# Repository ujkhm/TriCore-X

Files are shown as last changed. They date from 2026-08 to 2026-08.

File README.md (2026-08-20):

# Xeltri

> **Xeltri: a heterogeneous development board.**
> X = mixed heterogeneous cores, el = electronics, tri = three cores (MPU + MCU + FPGA).
> This board puts an FPGA, an MPU, and an MCU on one system. (in development)

#### Read the original Traditional Chinese version [here](README.zh-TW.md).

**Hackaday.io Project Page:** [Xeltri - Pick and Place Control Board](https://hackaday.io/project/206451-xeltri-pick-and-place-control-board)

---

### Project overview
This project is a main controller board built for a desktop pick-and-place (PnP) machine. The three cores — STM32H745XIH6 (MCU), XC7A35T-2CSG325C (FPGA), and V851S (MPU) — are locked in and work together. Expansion I/O so far: PCIe 2.1 ×2 (in a PCIe ×4 slot, wired to the FPGA) and a microSD card slot. Everything else is still TBD.

---

### How it started
I needed a pick-and-place machine, but buying one was too expensive, so I decided to build it myself. I was 15 when I started (25 June 2026). It began as a sudden “what if I just try?” thought, and I then committed to it as a long-term project. A lot of what this board needs is something I only know *what it is for*, not something I have actually designed before. I know this is hard, so please keep expectations modest — but it should not be terrible either.

---

### Board architecture and why these cores
Xeltri is built around STM32H745XIH6 (MCU), XC7A35T-2CSG325C (FPGA), and V851S (MPU). I chose this trio because I want to try mixed alignment: pure optical alignment for simple parts (0805, 0402, and similar packages), and a vision camera (OpenCV-style) for complex parts. I also want up-looking / down-looking cameras plus on-device AI for machine-health checks — that is why V851S is in the mix.

I am using pure optical alignment on simple parts because I want industrial on-the-fly (“flying shot”) speed, and the vision hardware that can actually do that is far too expensive. Optical alignment is much cheaper, but it needs real-time performance. The machine is meant to be a box-style CoreXY so it takes less floor space (like a Voron printer), which means a lot of structure and a lot of stepper motors to control. Closed-loop steppers with the servo drive in the motor base are too expensive for me, and the cheap ones are not fast enough. An FPGA can handle that and more — I want the finished machine to be strong, not merely usable. That is how this three-core combination ended up here.

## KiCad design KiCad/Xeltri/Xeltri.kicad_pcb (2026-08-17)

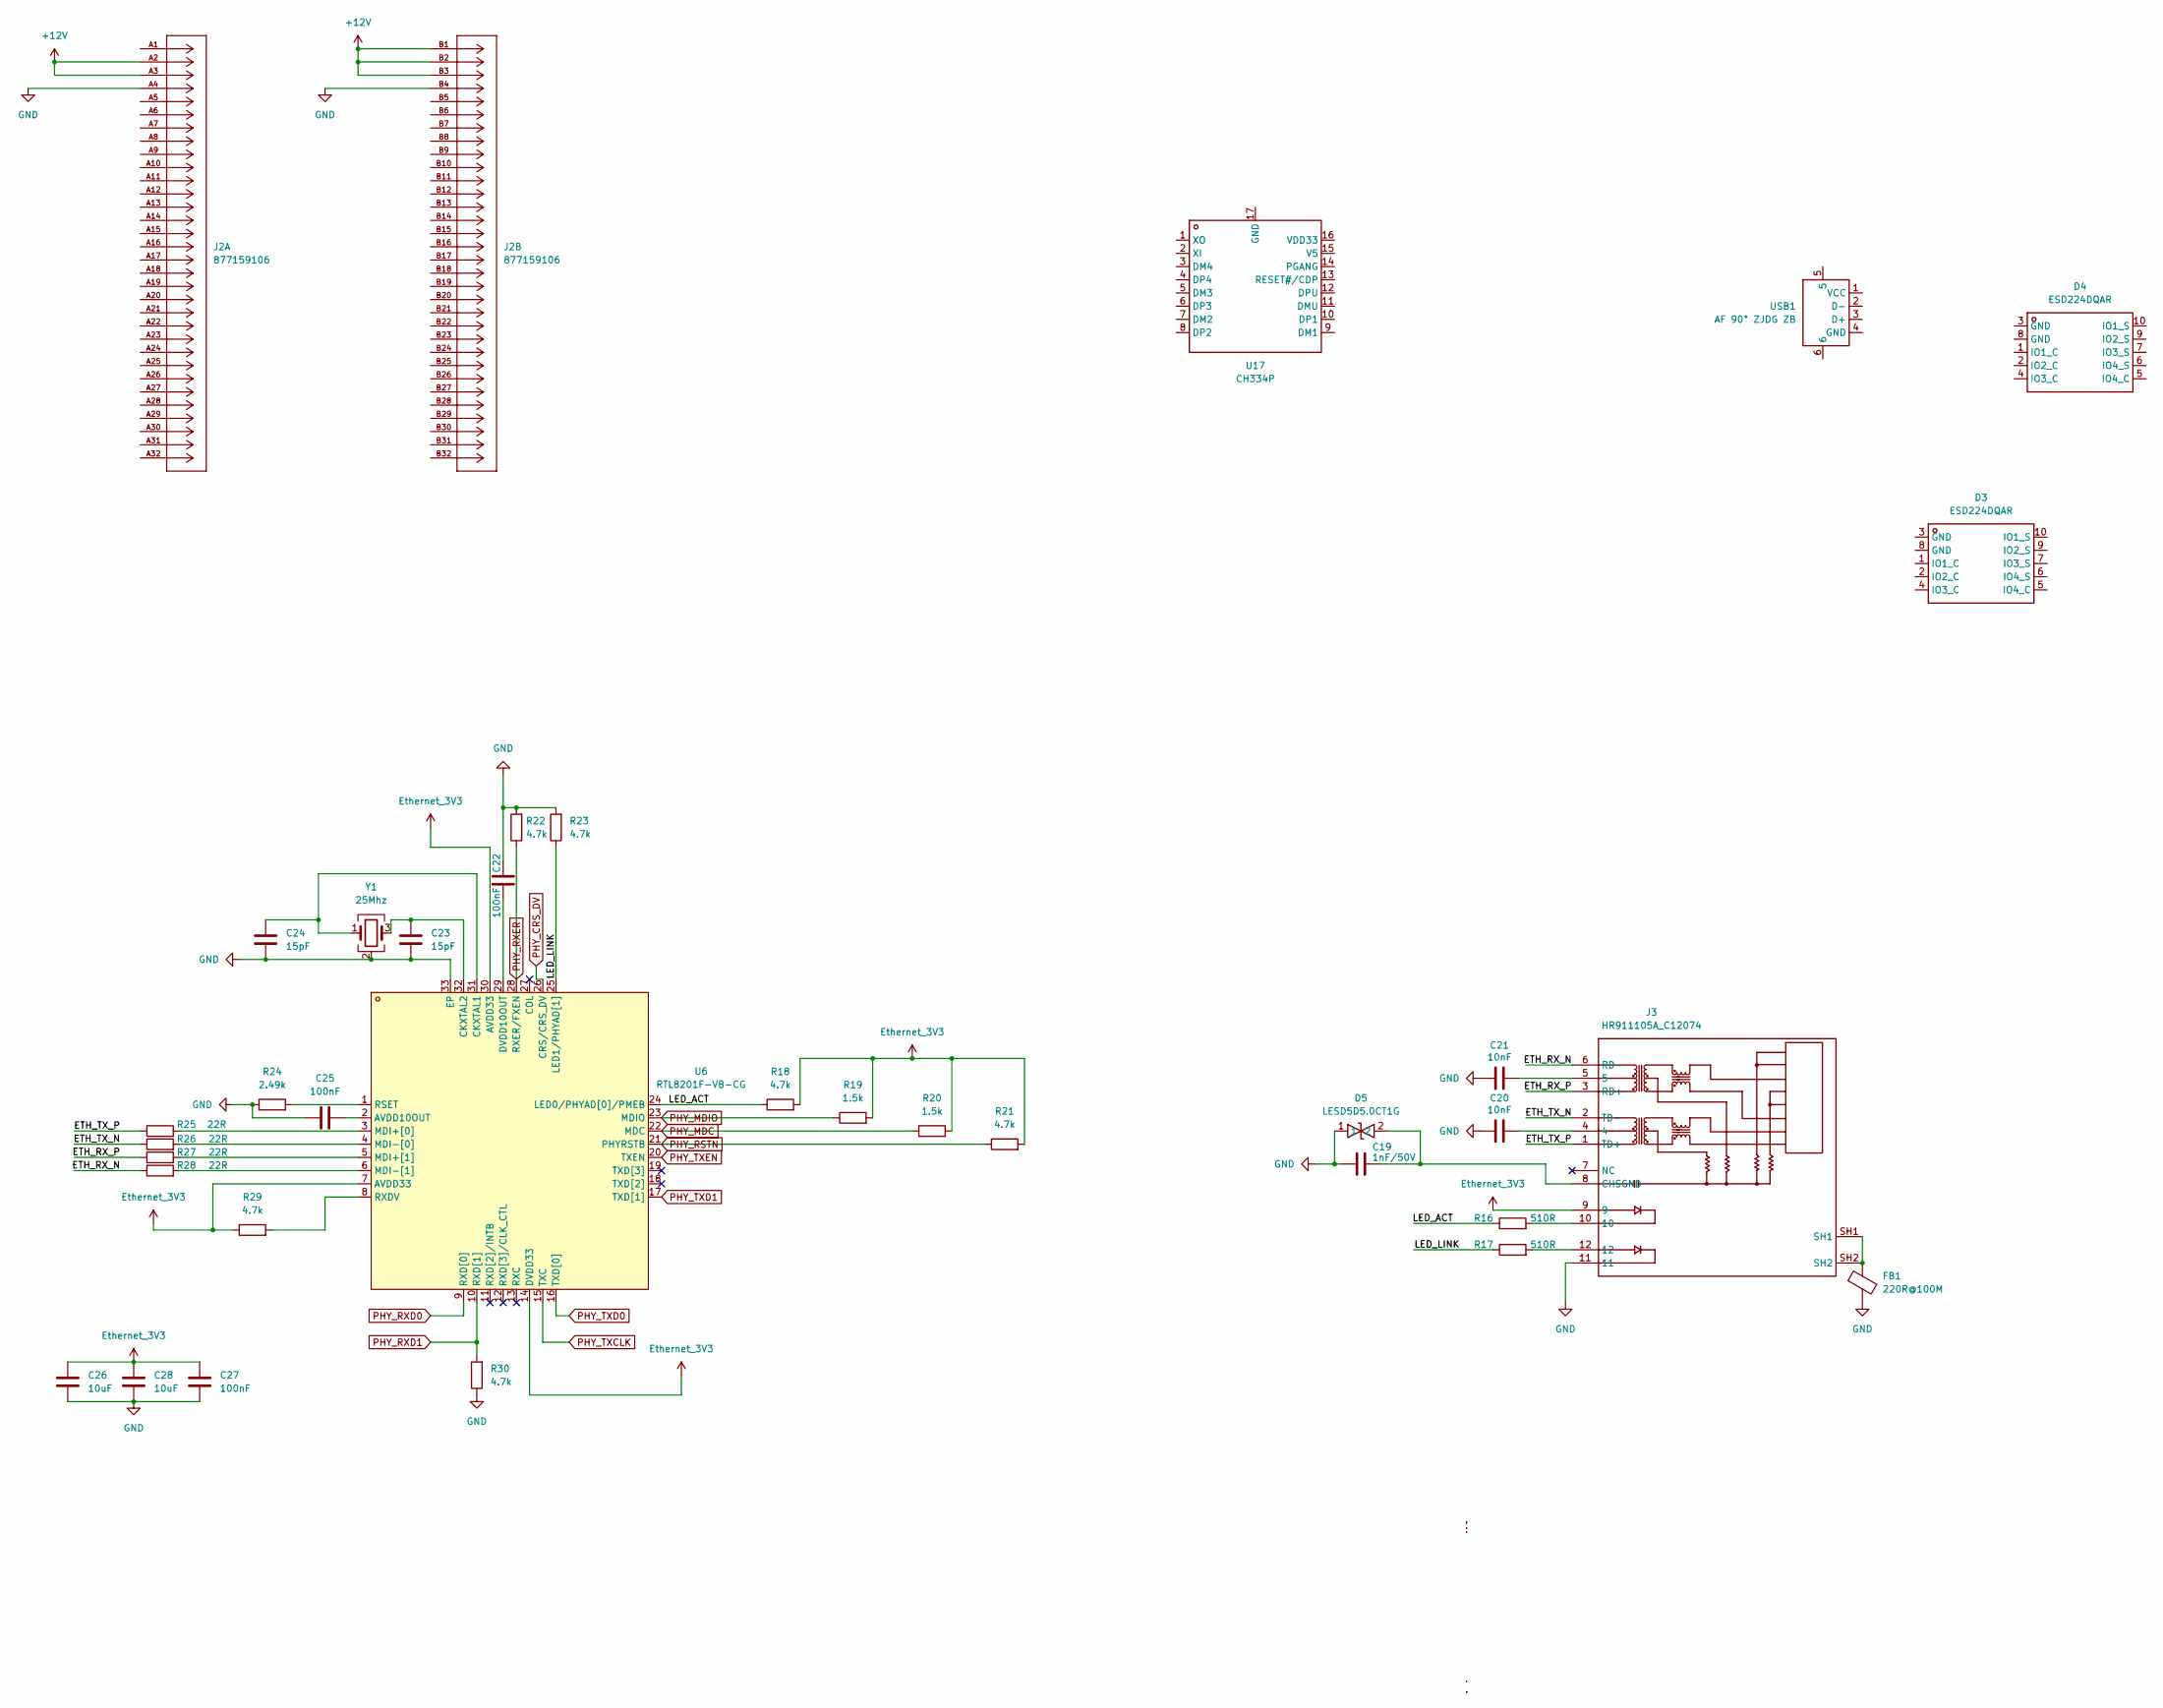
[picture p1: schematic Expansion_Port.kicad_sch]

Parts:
C19: 1nF/50V; C_0402_1005Metric
C20, C21: 10nF; C_0402_1005Metric
C22, C25, C27: 100nF; C_0402_1005Metric
C23, C24: 15pF; C_0402_1005Metric
C26, C28: 10uF; C_0402_1005Metric
D3, D4: ESD224DQAR; USON-10_L2.5-W1.0-P0.50-BL; LCSC Part C1981316
D5: LESD5D5.0CT1G; SOD-523_L1.2-W0.8-LS1.6-BI; LCSC Part C383211
FB1: 220R@100M; L_0603_1608Metric
J2: 877159106; CONN_87715-9106_MOL; MANUFACTURER_PART_NUMBER 877159106
J3: HR911105A_C12074; RJ45-TH_HR911105A; LCSC Part C12074
R16, R17: 510R; R_0402_1005Metric
R18, R21, R22, R23, R29, R30: 4.7k; R_0402_1005Metric
R19, R20: 1.5k; R_0402_1005Metric
R24: 2.49k; R_0402_1005Metric
R25, R26, R27, R28: 22R; R_0402_1005Metric
U6: RTL8201F-VB-CG; QFN-32_L5.0-W5.0-P0.50-BL-EP3.4; MPN RTL8201F-VB-CG; LCSC Part C45044
U17: CH334P; QFN-16_L3.0-W3.0-P0.50-BL-EP1.7; LCSC Part C5373042
USB1: AF 90° ZJDG ZB; USB-A-TH_AF-90-ZJDG-ZB; LCSC Part C6332182
Y1: 25Mhz; Crystal_SMD_3225-4Pin_3.2x2.5mm

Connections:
+12V: J2.A2, J2.A3, J2.B1, J2.B2, J2.B3; also elsewhere on the board
/Expansion_Port/ETH_RX_N: J3.6 (RD-), R28.1
/Expansion_Port/ETH_RX_P: J3.3 (RD+), R27.1
/Expansion_Port/ETH_TX_N: J3.2 (TD-), R26.1
/Expansion_Port/ETH_TX_P: J3.1 (TD+), R25.1
/Expansion_Port/LED_ACT: R16.1, R18.1, U6.24 (LED0/PHYAD[0]/PMEB)
/Expansion_Port/LED_LINK: R17.1, R23.1, U6.25 (LED1/PHYAD[1])
Ethernet_3V3: C26.1, C27.1, C28.1, J3.9, R18.2, R19.2, R20.2, R21.2, R29.1, U6.7 (AVDD33), U6.14 (DVDD33), U6.30 (AVDD33)
GND: C19.1, C20.1, C21.1, C22.2, C23.1, C24.1, C25.1, C26.2, C27.2, C28.2, D5.1, FB1.2, J2.A4, J2.B4, J3.11, R22.2, R23.2, R24.1, R30.1, U6.33 (EP), Y1.2 (G), Y1.4 (G); also elsewhere on the board
unnamed: C20.2, J3.4
unnamed: C21.2, J3.5
unnamed: FB1.1, J3.SH1, J3.SH2
unnamed: C19.2, D5.2, J3.8 (CHSGND)
unnamed: J3.10, R16.2
unnamed: J3.12, R17.2
unnamed: C25.2, U6.2 (AVDD10OUT)
unnamed: C24.2, U6.31 (CKXTAL1), Y1.1
unnamed: C23.2, U6.32 (CKXTAL2), Y1.3
unnamed: C22.1, U6.29 (DVDD10OUT)
unnamed: R25.2, U6.3 (MDI+[0])
unnamed: R27.2, U6.5 (MDI+[1])
unnamed: R26.2, U6.4 (MDI-[0])
unnamed: R28.2, U6.6 (MDI-[1])
unnamed: R24.2, U6.1 (RSET)
unnamed: R29.2, U6.8 (RXDV)
PHY_CRS_DV: U6.26 (CRS/CRS_DV)
PHY_MDC: R20.1, U6.22 (MDC)
PHY_MDIO: R19.1, U6.23 (MDIO)
PHY_RSTN: R21.1, U6.21 (PHYRSTB)
PHY_RXD0: U6.9 (RXD[0])
PHY_RXD1: R30.2, U6.10 (RXD[1])
PHY_RXER: R22.1, U6.28 (RXER/FXEN)
PHY_TXCLK: U6.15 (TXC)
PHY_TXD0: U6.16 (TXD[0])
PHY_TXD1: U6.17 (TXD[1])
PHY_TXEN: U6.20 (TXEN)

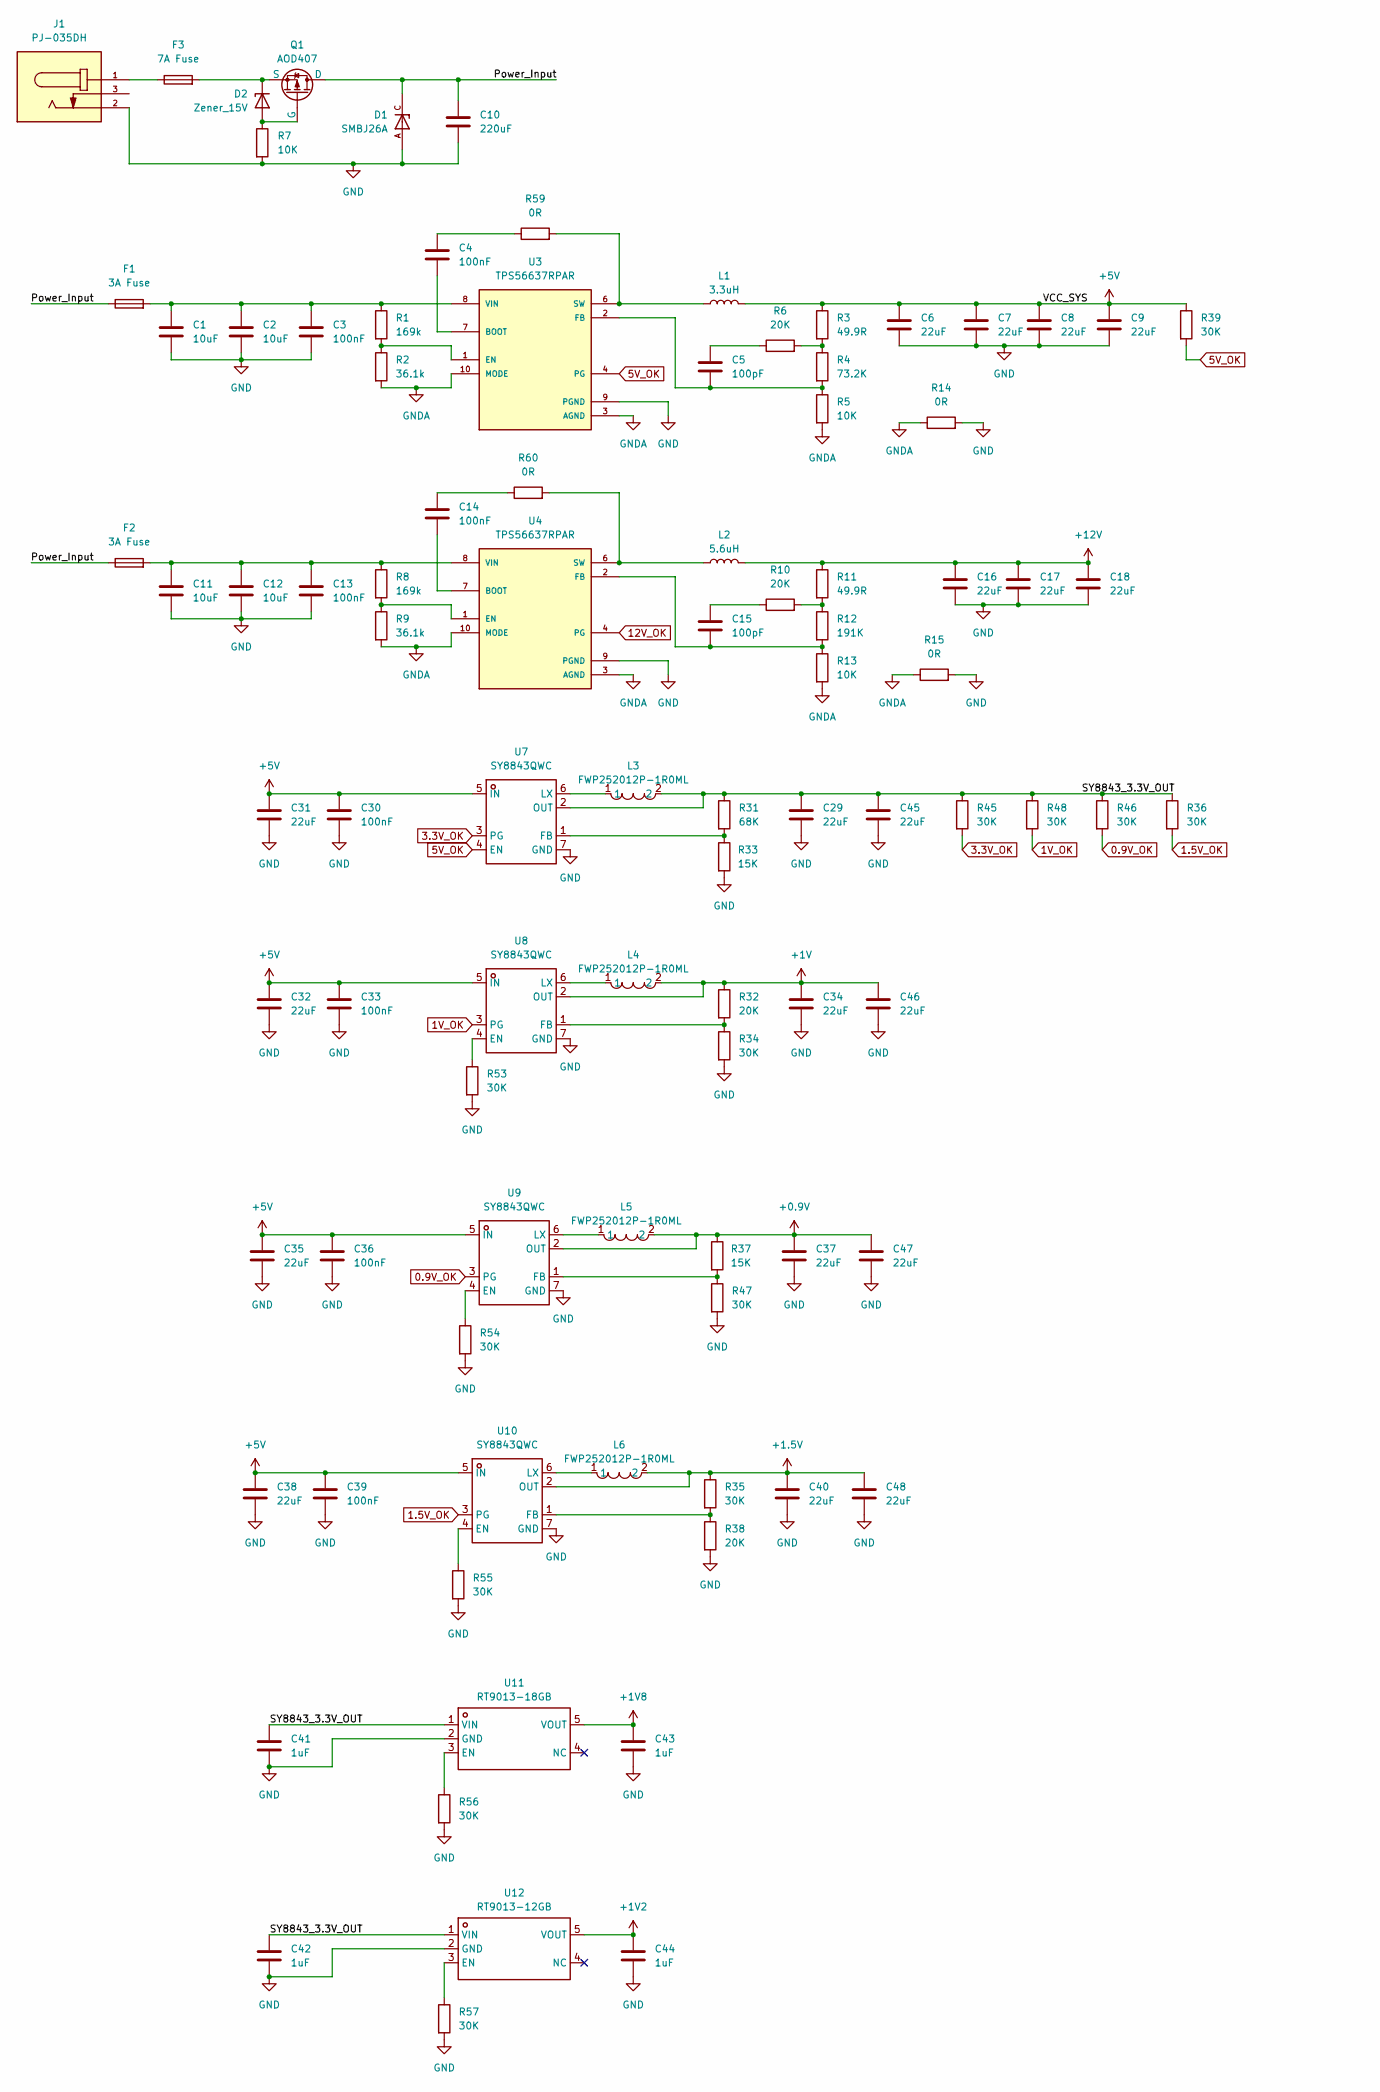
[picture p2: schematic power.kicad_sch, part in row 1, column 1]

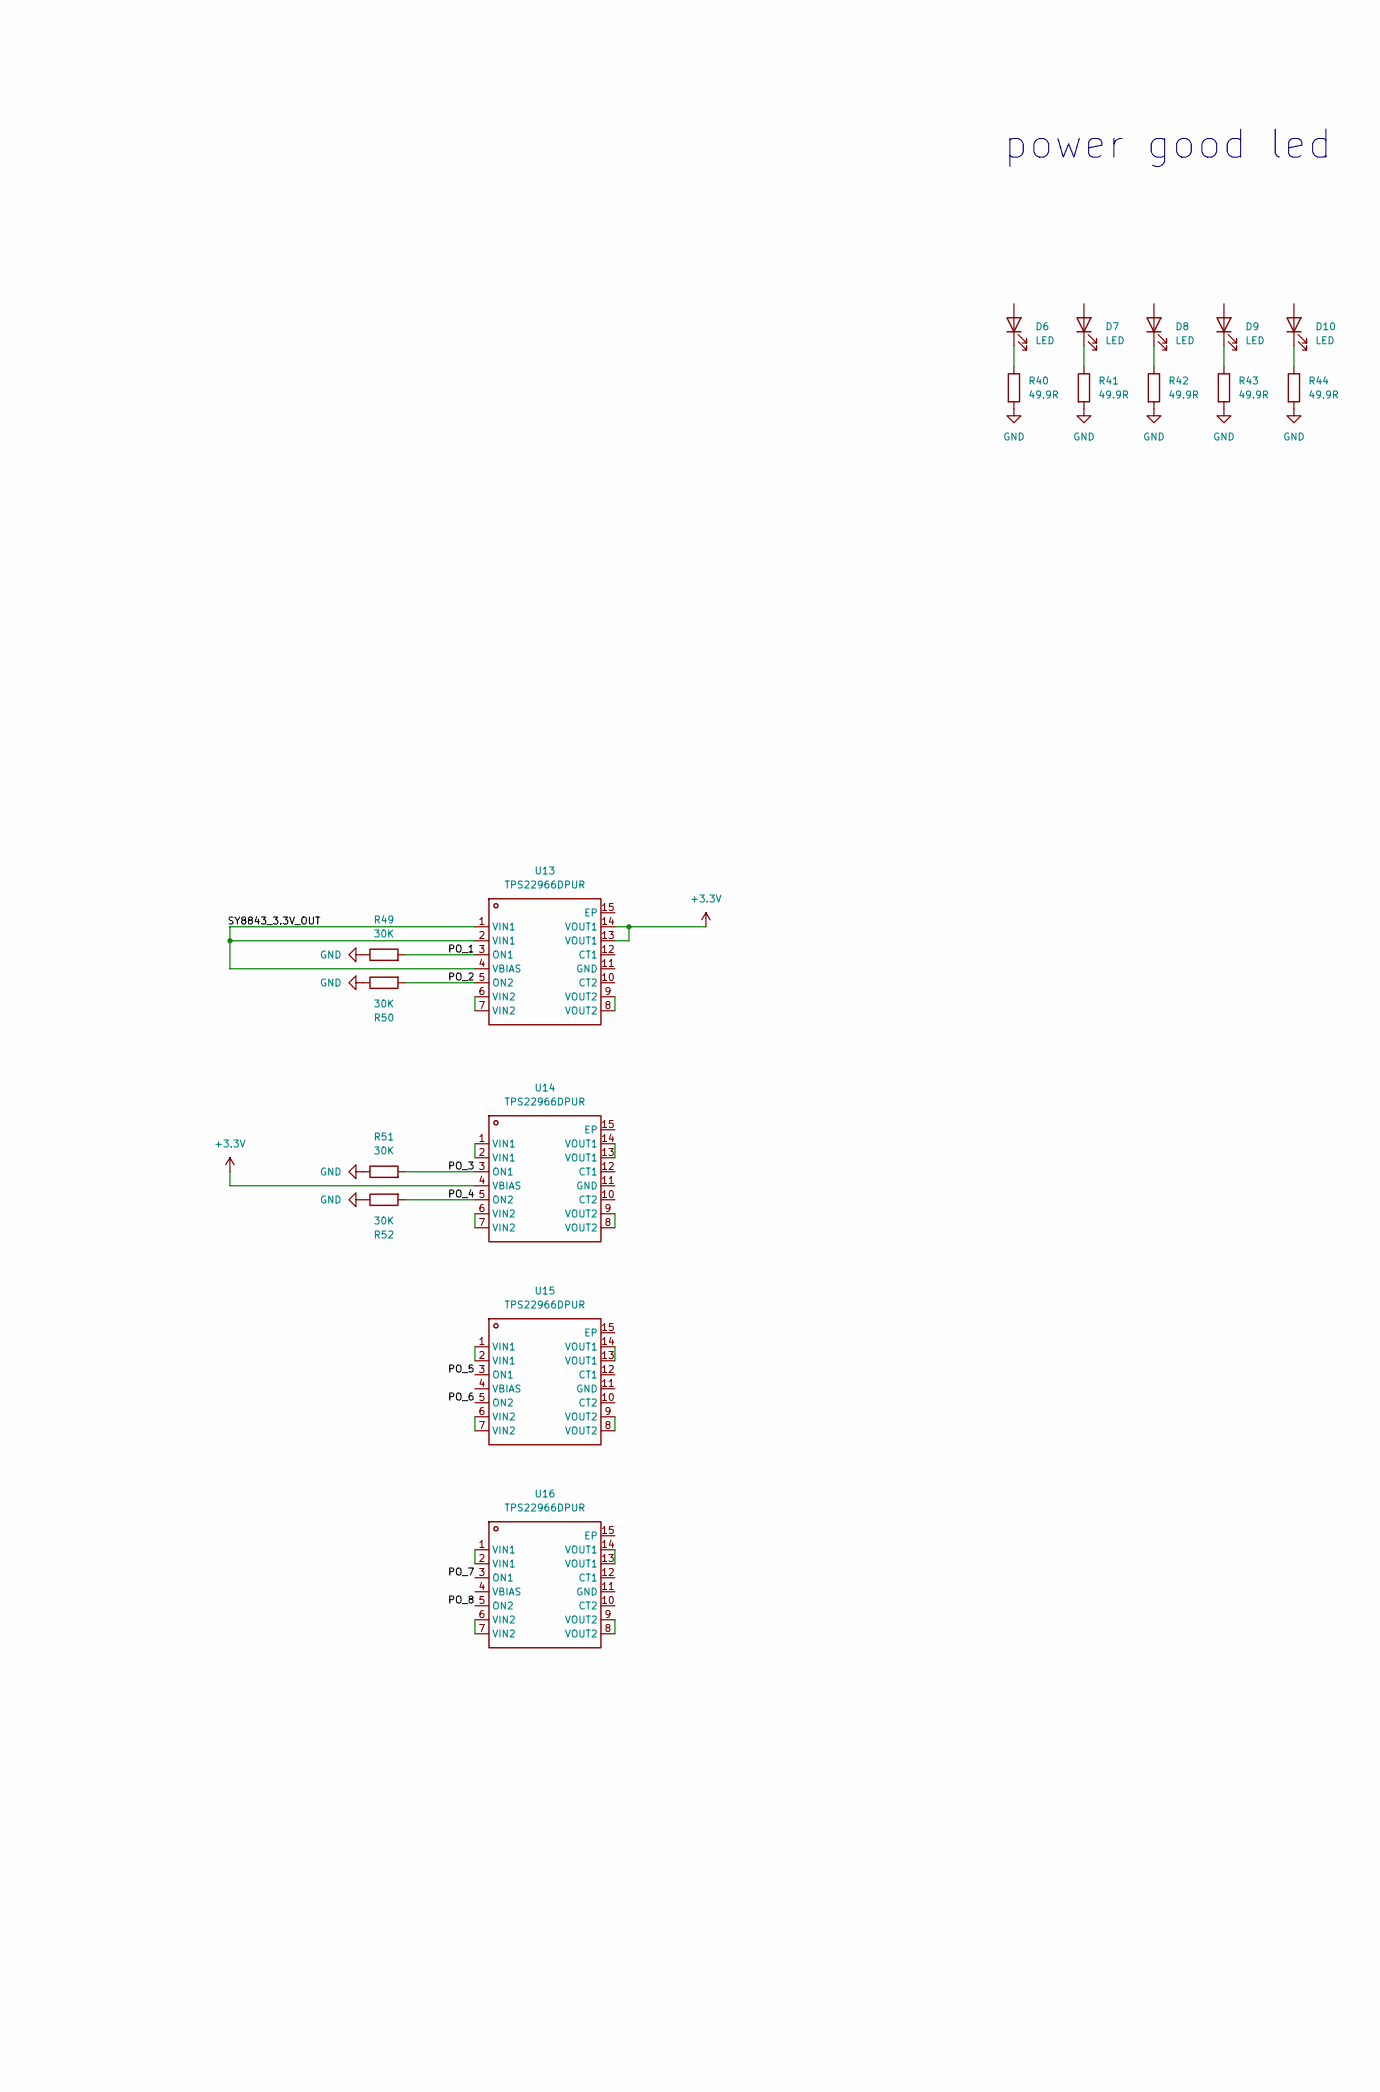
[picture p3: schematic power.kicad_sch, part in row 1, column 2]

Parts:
C1, C2, C11, C12: 10uF; C_1210_3225Metric
C3, C13: 100nF; C_0805_2012Metric
C4, C14, C30, C33, C36, C39: 100nF; C_0402_1005Metric
C5, C15: 100pF; C_0402_1005Metric
C6, C7, C8, C9, C16, C17, C18, C29, C31, C32, C34, C35, C37, C38, C40, C45, C46, C47, C48: 22uF; C_0805_2012Metric
C10: 220uF; C_Elec_8x10.2
C41, C42, C43, C44: 1uF; C_0402_1005Metric
D1: SMBJ26A; DIOM4336X265N; PARTREV F2102
D2: Zener_15V; D_SOD-123
D6, D7, D8, D9, D10: LED; LED_0603_1608Metric
F1, F2: 3A Fuse; Fuse_1206_3216Metric
F3: 7A Fuse; Fuse_1206_3216Metric
J1: PJ-035DH; CUI_PJ-035DH; PARTREV 1.05
L1: 3.3uH; L_Bourns_SRP7028A_7.3x6.6mm
L2: 5.6uH; L_Bourns_SRP7028A_7.3x6.6mm
L3, L4, L5, L6: FWP252012P-1R0ML; IND-SMD_L2.5-W2.0_YXMBL252010P; LCSC Part C5179444
Q1: AOD407; TO-252-2
R1, R8: 169k; R_0402_1005Metric
R2, R9: 36.1k; R_0402_1005Metric
R3, R11, R40, R41, R42, R43, R44: 49.9R; R_0402_1005Metric
R4: 73.2K; R_0402_1005Metric
R5, R7, R13: 10K; R_0402_1005Metric
R6, R10, R32, R38: 20K; R_0402_1005Metric
R12: 191K; R_0402_1005Metric
R14, R15, R59, R60: 0R; R_0402_1005Metric
R31: 68K; R_0402_1005Metric
R33, R37: 15K; R_0402_1005Metric
R34, R35, R36, R39, R45, R46, R47, R48, R49, R50, R51, R52, R53, R54, R55, R56, R57: 30K; R_0402_1005Metric
U3, U4: TPS56637RPAR; CONV_TPS56637RPAR; PARTREV A
U7, U8, U9, U10: SY8843QWC; QFN-7_L1.5-W1.5-P0.45-BL_SILERGY_SY8842QWC; LCSC Part C3151906
U11: RT9013-18GB; SOT-23-5_L3.0-W1.7-P0.95-LS2.8-BR; LCSC Part C59969
U12: RT9013-12GB; SOT-23-5_L3.0-W1.7-P0.95-LS2.8-BR; LCSC Part C58464
U13, U14, U15, U16: TPS22966DPUR; WSON-14_L3.0-W2.0-P0.40-BL-EP; LCSC Part C398913

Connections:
0.9V_OK: R46.2, U9.3 (PG)
1.5V_OK: R36.2, U10.3 (PG)
1V_OK: R48.2, U8.3 (PG)
3.3V_OK: R45.2, U7.3 (PG)
5V_OK: R39.2, U3.4 (PG), U7.4 (EN)
12V_OK: U4.4 (PG)
+0.9V: C37.1, C47.1, L5.2, R37.1, U9.2 (OUT)
+1.5V: C40.1, C48.1, L6.2, R35.1, U10.2 (OUT)
+1V: C34.1, C46.1, L4.2, R32.1, U8.2 (OUT)
+1V2: C44.1, U12.5 (VOUT)
+1V8: C43.1, U11.5 (VOUT)
+3.3V: U13.13 (VOUT1), U13.14 (VOUT1), U14.4 (VBIAS); also elsewhere on the board
+5V: C6.1, C7.1, C8.1, C9.1, C30.1, C31.1, C32.1, C33.1, C35.1, C36.1, C38.1, C39.1, L1.2, R3.1, R39.1, U7.5 (IN), U8.5 (IN), U9.5 (IN), U10.5 (IN)
+12V: C16.1, C17.1, C18.1, L2.2, R11.1; also elsewhere on the board
/power/PO_1: R49.2, U13.3 (ON1)
/power/PO_2: R50.2, U13.5 (ON2)
/power/PO_3: R51.2, U14.3 (ON1)
/power/PO_4: R52.2, U14.5 (ON2)
/power/PO_5: U15.3 (ON1)
/power/PO_6: U15.5 (ON2)
/power/PO_7: U16.3 (ON1)
/power/PO_8: U16.5 (ON2)
/power/Power_Input: C10.1, D1.C, F1.1, F2.1, Q1.1 (D)
/power/SY8843_3.3V_OUT: C29.1, C41.1, C42.1, C45.1, L3.2, R31.1, R36.1, R45.1, R46.1, R48.1, U7.2 (OUT), U11.1 (VIN), U12.1 (VIN), U13.1 (VIN1), U13.2 (VIN1), U13.4 (VBIAS)
GND: C1.2, C2.2, C3.2, C6.2, C7.2, C8.2, C9.2, C10.2, C11.2, C12.2, C13.2, C16.2, C17.2, C18.2, C29.2, C30.2, C31.2, C32.2, C33.2, C34.2, C35.2, C36.2, C37.2, C38.2, C39.2, C40.2, C41.2, C42.2, C43.2, C44.2, C45.2, C46.2, C47.2, C48.2, D1.A, J1.2, R7.2, R14.2, R15.2, R33.2, R34.2, R38.2, R40.2, R41.2, R42.2, R43.2, R44.2, R47.2, R49.1, R50.1, R51.1, R52.1, R53.2, R54.2, R55.2, R56.2, R57.2, U3.9 (PGND), U4.9 (PGND), U7.7 (GND), U8.7 (GND), U9.7 (GND), U10.7 (GND), U11.2 (GND), U12.2 (GND); also elsewhere on the board
GNDA: R2.2, R5.2, R9.2, R13.2, R14.1, R15.1, U3.3 (AGND), U3.10 (MODE), U4.3 (AGND), U4.10 (MODE)
unnamed: C4.2, R59.1
unnamed: C5.1, R6.1
unnamed: C14.2, R60.1
unnamed: C15.1, R10.1
unnamed: D2.2 (A), Q1.2 (G), R7.1
unnamed: D2.1 (K), F3.2, Q1.3 (S)
unnamed: D6.1 (K), R40.1
unnamed: D7.1 (K), R41.1
unnamed: D8.1 (K), R42.1
unnamed: D9.1 (K), R43.1
unnamed: D10.1 (K), R44.1
unnamed: F3.1, J1.1
unnamed: R3.2, R4.1, R6.2
unnamed: R10.2, R11.2, R12.1
unnamed: C4.1, U3.7 (BOOT)
unnamed: R1.2, R2.1, U3.1 (EN)
unnamed: C5.2, R4.2, R5.1, U3.2 (FB)
unnamed: L1.1, R59.2, U3.6 (SW)
unnamed: C1.1, C2.1, C3.1, F1.2, R1.1, U3.8 (VIN)
unnamed: C14.1, U4.7 (BOOT)
unnamed: R8.2, R9.1, U4.1 (EN)
unnamed: C15.2, R12.2, R13.1, U4.2 (FB)
unnamed: L2.1, R60.2, U4.6 (SW)
unnamed: C11.1, C12.1, C13.1, F2.2, R8.1, U4.8 (VIN)
unnamed: R31.2, R33.1, U7.1 (FB)
unnamed: L3.1, U7.6 (LX)
unnamed: R53.1, U8.4 (EN)
unnamed: R32.2, R34.1, U8.1 (FB)
unnamed: L4.1, U8.6 (LX)
unnamed: R54.1, U9.4 (EN)
unnamed: R37.2, R47.1, U9.1 (FB)
unnamed: L5.1, U9.6 (LX)
unnamed: R55.1, U10.4 (EN)
unnamed: R35.2, R38.1, U10.1 (FB)
unnamed: L6.1, U10.6 (LX)
unnamed: R56.1, U11.3 (EN)
unnamed: R57.1, U12.3 (EN)
unnamed: U13.6 (VIN2), U13.7 (VIN2)
unnamed: U13.8 (VOUT2), U13.9 (VOUT2)
unnamed: U14.1 (VIN1), U14.2 (VIN1)
unnamed: U14.6 (VIN2), U14.7 (VIN2)
unnamed: U14.13 (VOUT1), U14.14 (VOUT1)
unnamed: U14.8 (VOUT2), U14.9 (VOUT2)
unnamed: U15.1 (VIN1), U15.2 (VIN1)
unnamed: U15.6 (VIN2), U15.7 (VIN2)
unnamed: U15.13 (VOUT1), U15.14 (VOUT1)
unnamed: U15.8 (VOUT2), U15.9 (VOUT2)
unnamed: U16.1 (VIN1), U16.2 (VIN1)
unnamed: U16.6 (VIN2), U16.7 (VIN2)
unnamed: U16.13 (VOUT1), U16.14 (VOUT1)
unnamed: U16.8 (VOUT2), U16.9 (VOUT2)

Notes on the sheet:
power good led

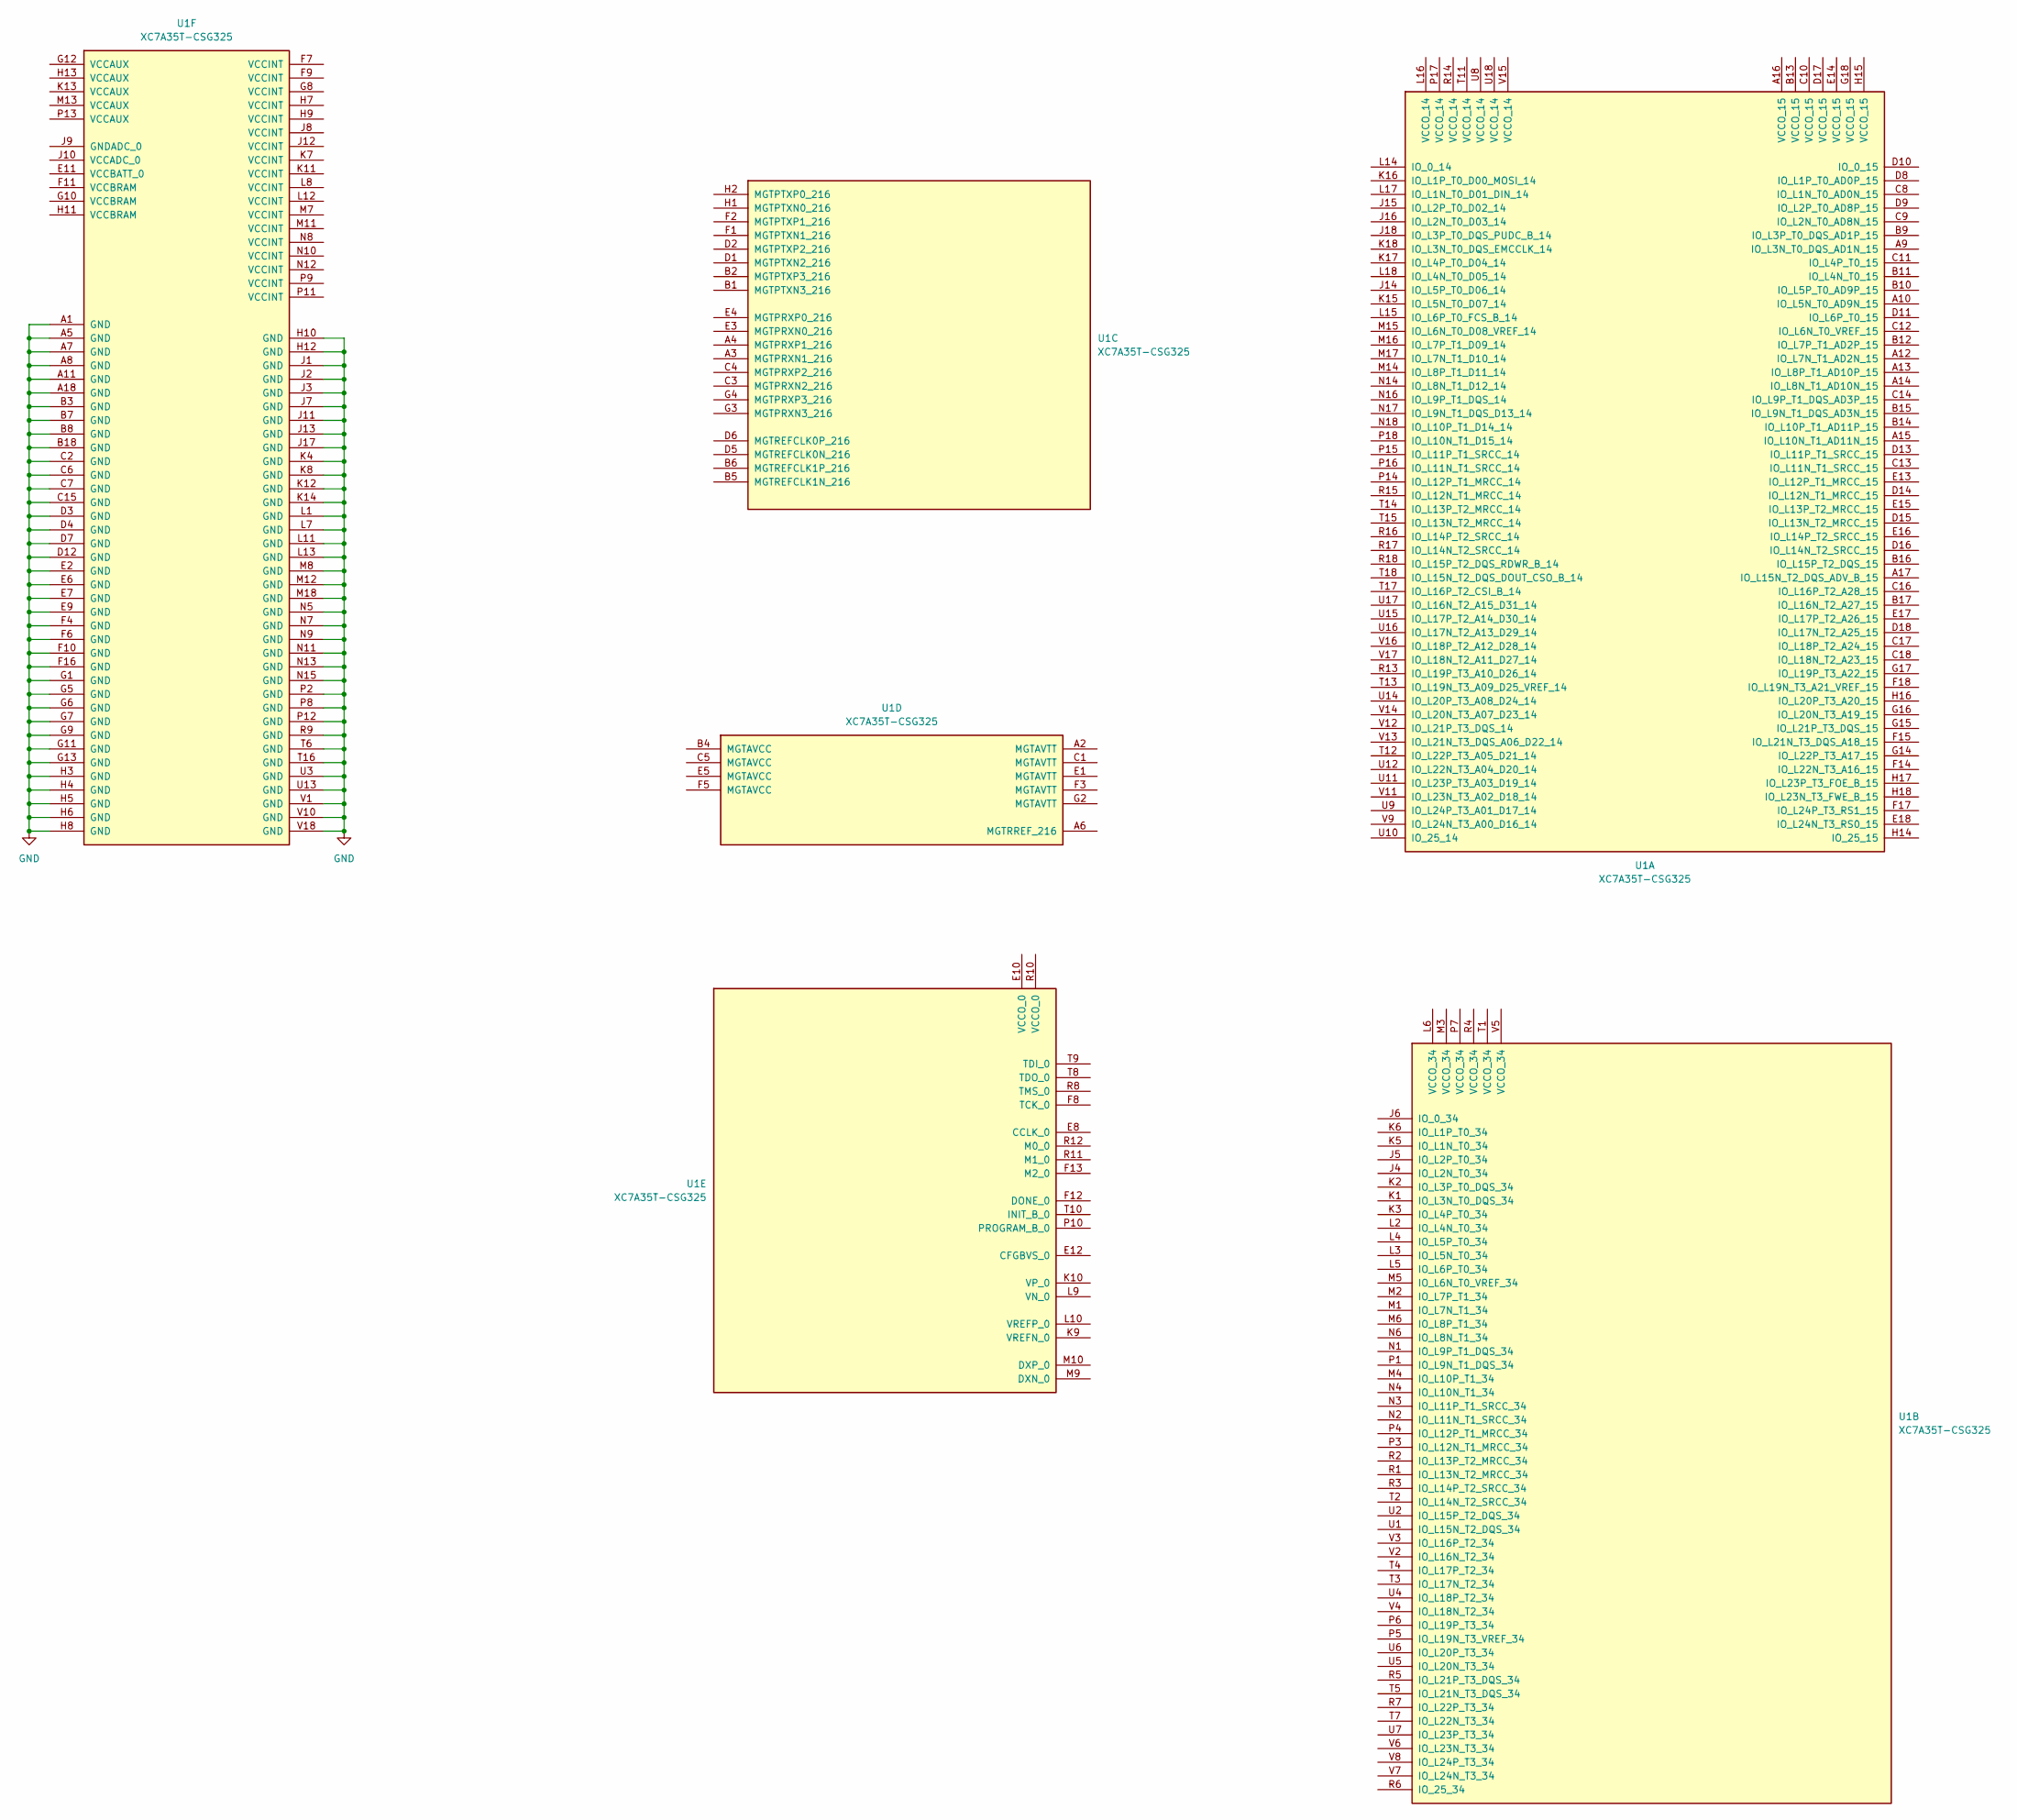
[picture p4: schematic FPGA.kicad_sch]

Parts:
U1: XC7A35T-CSG325; Xilinx_CSG325

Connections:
GND: U1.A1 (GND), U1.A5 (GND), U1.A7 (GND), U1.A8 (GND), U1.A11 (GND), U1.A18 (GND), U1.B3 (GND), U1.B7 (GND), U1.B8 (GND), U1.B18 (GND), U1.C2 (GND), U1.C6 (GND), U1.C7 (GND), U1.C15 (GND), U1.D3 (GND), U1.D4 (GND), U1.D7 (GND), U1.D12 (GND), U1.E2 (GND), U1.E6 (GND), U1.E7 (GND), U1.E9 (GND), U1.F4 (GND), U1.F6 (GND), U1.F10 (GND), U1.F16 (GND), U1.G1 (GND), U1.G5 (GND), U1.G6 (GND), U1.G7 (GND), U1.G9 (GND), U1.G11 (GND), U1.G13 (GND), U1.H3 (GND), U1.H4 (GND), U1.H5 (GND), U1.H6 (GND), U1.H8 (GND), U1.H10 (GND), U1.H12 (GND), U1.J1 (GND), U1.J2 (GND), U1.J3 (GND), U1.J7 (GND), U1.J11 (GND), U1.J13 (GND), U1.J17 (GND), U1.K4 (GND), U1.K8 (GND), U1.K12 (GND), U1.K14 (GND), U1.L1 (GND), U1.L7 (GND), U1.L11 (GND), U1.L13 (GND), U1.M8 (GND), U1.M12 (GND), U1.M18 (GND), U1.N5 (GND), U1.N7 (GND), U1.N9 (GND), U1.N11 (GND), U1.N13 (GND), U1.N15 (GND), U1.P2 (GND), U1.P8 (GND), U1.P12 (GND), U1.R9 (GND), U1.T6 (GND), U1.T16 (GND), U1.U3 (GND), U1.U13 (GND), U1.V1 (GND), U1.V10 (GND), U1.V18 (GND); also elsewhere on the board

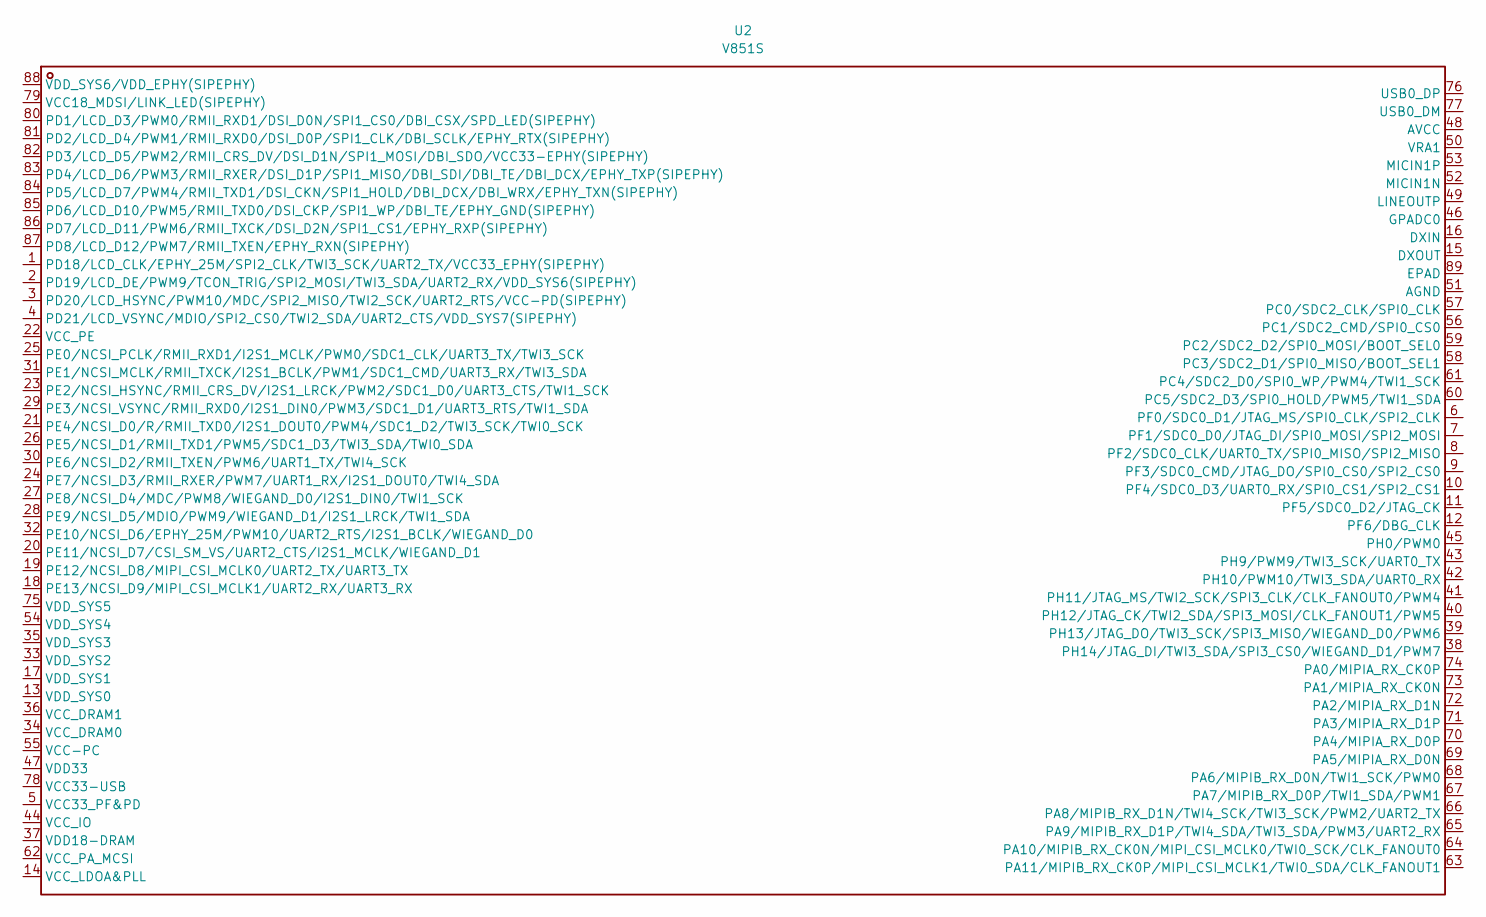
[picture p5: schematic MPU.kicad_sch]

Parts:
U2: V851S; QFN-88_L9.0-W9.0-P0.35-TL-EP6.5; LCSC Part C5365286

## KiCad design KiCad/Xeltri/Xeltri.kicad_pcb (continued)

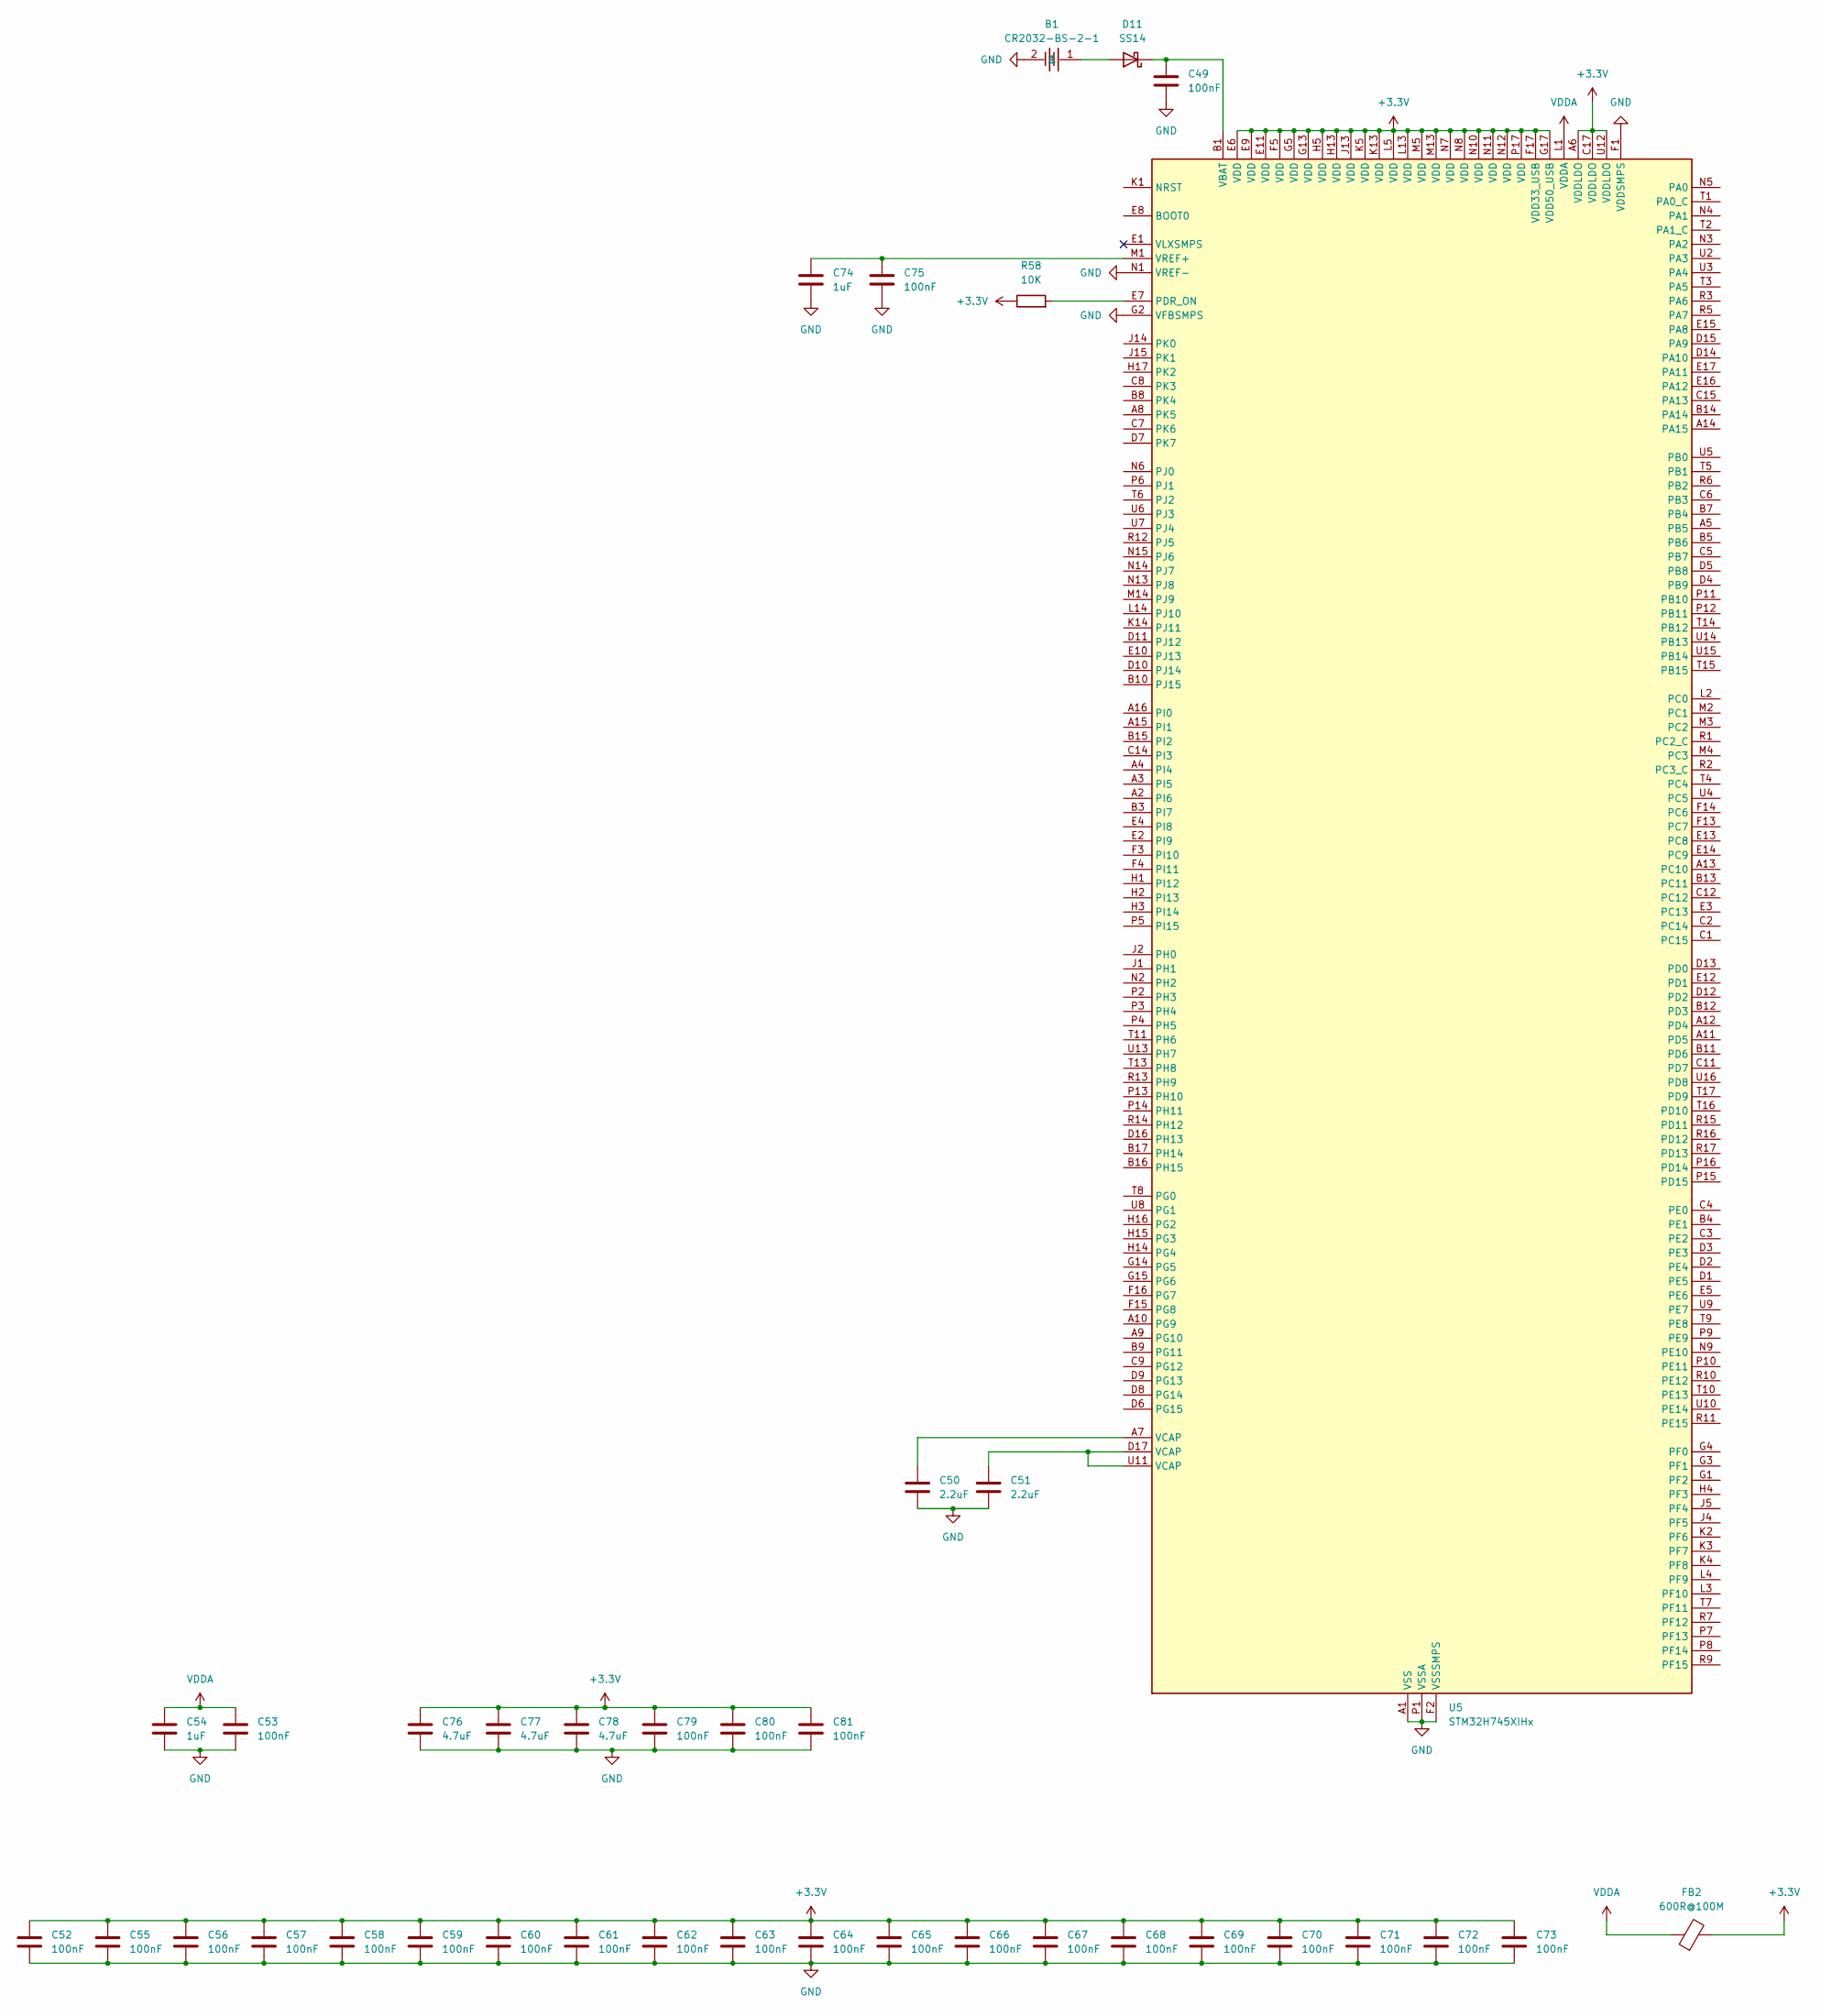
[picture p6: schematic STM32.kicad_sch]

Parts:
B1: CR2032-BS-2-1; BAT-TH_BS-2-1; LCSC Part C70376
C49, C52, C53, C55, C56, C57, C58, C59, C60, C61, C62, C63, C64, C65, C66, C67, C68, C69, C70, C71, C72, C73, C75, C79, C80, C81: 100nF; C_0402_1005Metric
C50, C51: 2.2uF; C_0402_1005Metric
C54, C74: 1uF; C_0402_1005Metric
C76, C77, C78: 4.7uF; C_0805_2012Metric
D11: SS14; D_SMA
FB2: 600R@100M; L_0402_1005Metric
R58: 10K; R_0402_1005Metric
U5: STM32H745XIHx; TFBGA-265_14x14mm_Layout17x17_P0.8mm

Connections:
+3.3V: C52.1, C55.1, C56.1, C57.1, C58.1, C59.1, C60.1, C61.1, C62.1, C63.1, C64.1, C65.1, C66.1, C67.1, C68.1, C69.1, C70.1, C71.1, C72.1, C73.1, C76.1, C77.1, C78.1, C79.1, C80.1, C81.1, FB2.2, R58.1, U5.A6 (VDDLDO), U5.C17 (VDDLDO), U5.E6 (VDD), U5.E9 (VDD), U5.E11 (VDD), U5.F5 (VDD), U5.F17 (VDD33_USB), U5.G5 (VDD), U5.G13 (VDD), U5.G17 (VDD50_USB), U5.H5 (VDD), U5.H13 (VDD), U5.J13 (VDD), U5.K5 (VDD), U5.K13 (VDD), U5.L5 (VDD), U5.L13 (VDD), U5.M5 (VDD), U5.M13 (VDD), U5.N7 (VDD), U5.N8 (VDD), U5.N10 (VDD), U5.N11 (VDD), U5.N12 (VDD), U5.P17 (VDD), U5.U12 (VDDLDO); also elsewhere on the board
GND: B1.2, C49.2, C50.1, C51.2, C52.2, C53.2, C54.2, C55.2, C56.2, C57.2, C58.2, C59.2, C60.2, C61.2, C62.2, C63.2, C64.2, C65.2, C66.2, C67.2, C68.2, C69.2, C70.2, C71.2, C72.2, C73.2, C74.2, C75.2, C76.2, C77.2, C78.2, C79.2, C80.2, C81.2, U5.A1 (VSS), U5.A17 (VSS), U5.B2 (VSS), U5.B6 (VSS), U5.C10 (VSS), U5.C13 (VSS), U5.C16 (VSS), U5.F1 (VDDSMPS), U5.F2 (VSSSMPS), U5.G2 (VFBSMPS), U5.G7 (VSS), U5.G8 (VSS), U5.G9 (VSS), U5.G10 (VSS), U5.G11 (VSS), U5.G16 (VSS), U5.H7 (VSS), U5.H8 (VSS), U5.H9 (VSS), U5.H10 (VSS), U5.H11 (VSS), U5.J3 (VSS), U5.J7 (VSS), U5.J8 (VSS), U5.J9 (VSS), U5.J10 (VSS), U5.J11 (VSS), U5.J16 (VSS), U5.J17 (VSS), U5.K7 (VSS), U5.K8 (VSS), U5.K9 (VSS), U5.K10 (VSS), U5.K11 (VSS), U5.K15 (VSS), U5.L7 (VSS), U5.L8 (VSS), U5.L9 (VSS), U5.L10 (VSS), U5.L11 (VSS), U5.L15 (VSS), U5.M15 (VSS), U5.N1 (VREF-), U5.N16 (VSS), U5.P1 (VSSA), U5.R4 (VSS), U5.R8 (VSS), U5.T12 (VSS), U5.U1 (VSS), U5.U17 (VSS); also elsewhere on the board
unnamed: C50.2, U5.A7 (VCAP)
unnamed: C51.1, U5.D17 (VCAP), U5.U11 (VCAP)
unnamed: B1.1, D11.2 (A)
unnamed: C49.1, D11.1 (K), U5.B1 (VBAT)
unnamed: R58.2, U5.E7 (PDR_ON)
unnamed: C74.1, C75.1, U5.M1 (VREF+)
VDDA: C53.1, C54.1, FB2.1, U5.L1 (VDDA)

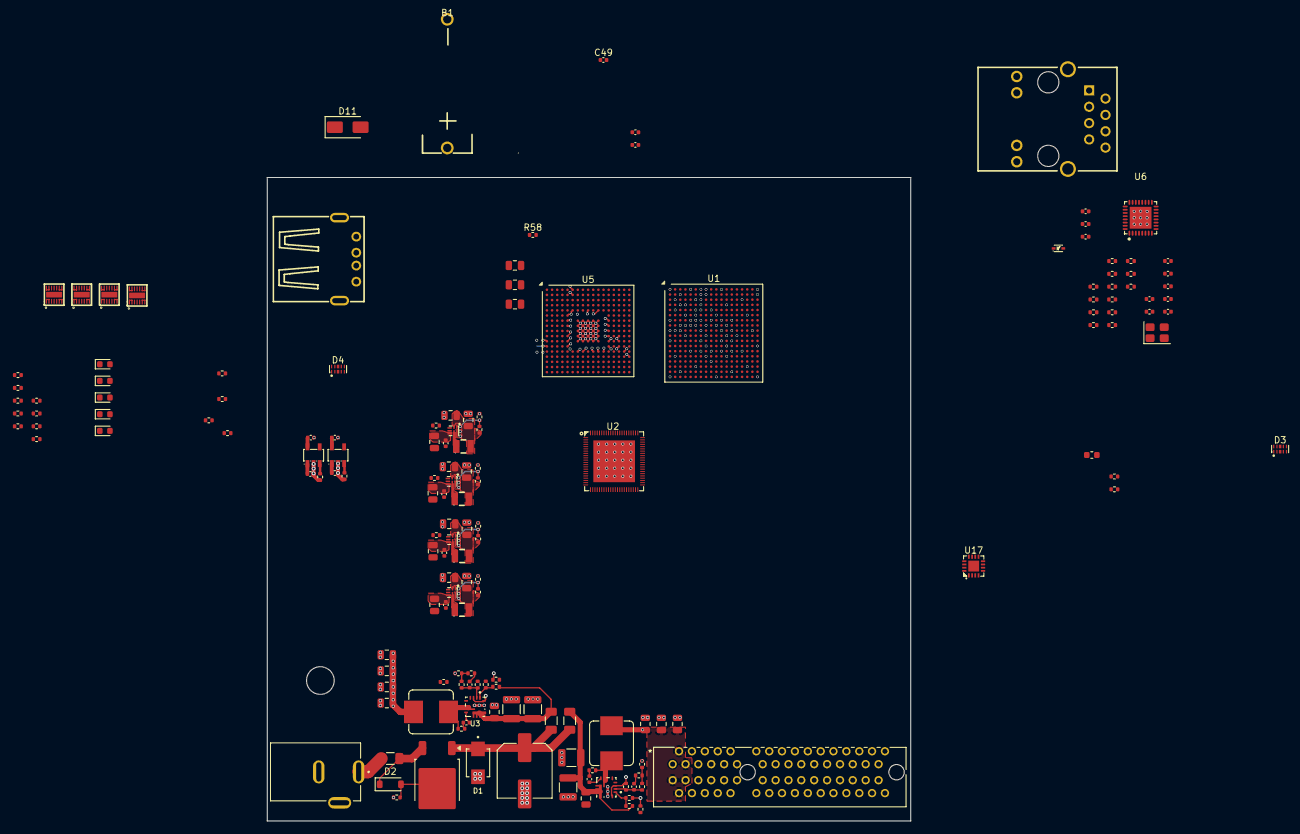
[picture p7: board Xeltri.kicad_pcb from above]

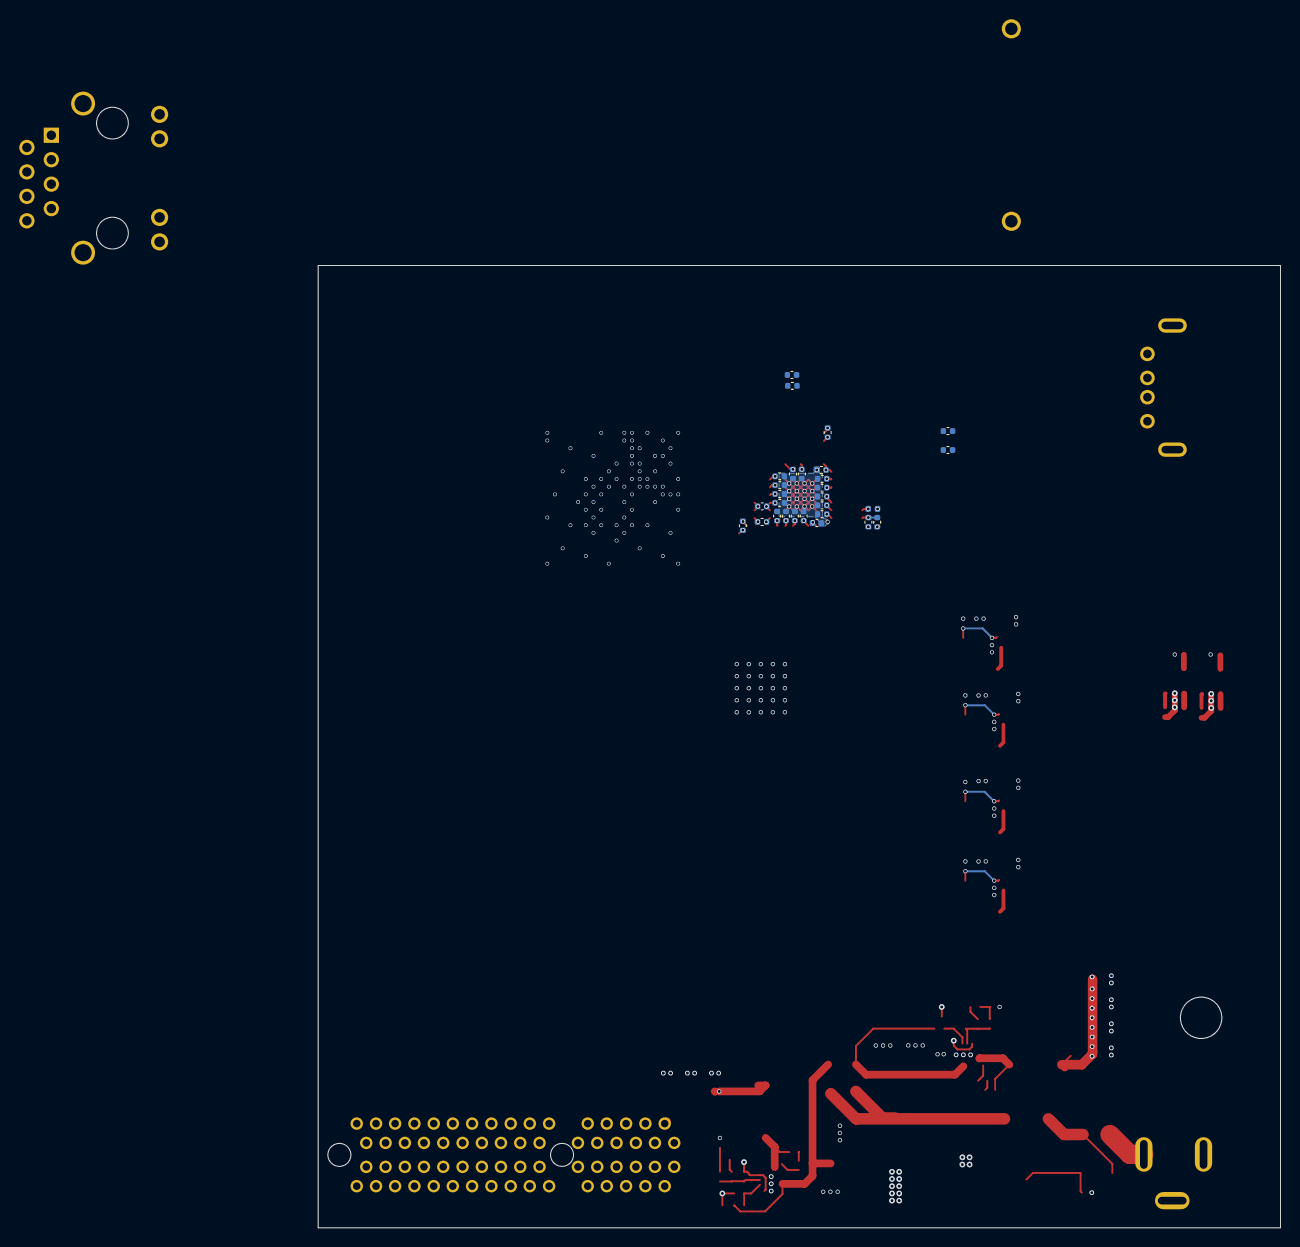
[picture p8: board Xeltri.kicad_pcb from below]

Board: 6 copper layers, 100.0 x 100.0 mm, 187 parts (28 on the bottom side), 107 nets.

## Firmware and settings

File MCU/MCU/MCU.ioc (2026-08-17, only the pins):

Mcu.UserName=STM32H745XIHx
PC0.Signal=FMC_SDNWE
PC2.Signal=FMC_SDNE0
PC3.Signal=FMC_SDCKE0
PD0.Signal=FMC_D2_DA2
PD1.Signal=FMC_D3_DA3
PD10.Signal=FMC_D15_DA15
PD14.Signal=FMC_D0_DA0
PD15.Signal=FMC_D1_DA1
PD8.Signal=FMC_D13_DA13
PD9.Signal=FMC_D14_DA14
PE0.Signal=FMC_NBL0
PE1.Signal=FMC_NBL1
PE10.Signal=FMC_D7_DA7
PE11.Signal=FMC_D8_DA8
PE12.Signal=FMC_D9_DA9
PE13.Signal=FMC_D10_DA10
PE14.Signal=FMC_D11_DA11
PE15.Signal=FMC_D12_DA12
PE7.Signal=FMC_D4_DA4
PE8.Signal=FMC_D5_DA5
PE9.Signal=FMC_D6_DA6
PF0.Signal=FMC_A0
PF1.Signal=FMC_A1
PF11.Signal=FMC_SDNRAS
PF12.Signal=FMC_A6
PF13.Signal=FMC_A7
PF14.Signal=FMC_A8
PF15.Signal=FMC_A9
PF2.Signal=FMC_A2
PF3.Signal=FMC_A3
PF4.Signal=FMC_A4
PF5.Signal=FMC_A5
PG0.Signal=FMC_A10
PG1.Signal=FMC_A11
PG15.Signal=FMC_SDNCAS
PG2.Signal=FMC_A12
PG4.Signal=FMC_A14_BA0
PG5.Signal=FMC_A15_BA1
PG8.Signal=FMC_SDCLK
PH10.Signal=FMC_D18
PH11.Signal=FMC_D19
PH12.Signal=FMC_D20
PH13.Signal=FMC_D21
PH14.Signal=FMC_D22
PH15.Signal=FMC_D23
PH8.Signal=FMC_D16
PH9.Signal=FMC_D17
PI0.Signal=FMC_D24
PI1.Signal=FMC_D25
PI10.Signal=FMC_D31
PI2.Signal=FMC_D26
PI3.Signal=FMC_D27
PI4.Signal=FMC_NBL2
PI5.Signal=FMC_NBL3
PI6.Signal=FMC_D28
PI7.Signal=FMC_D29
PI9.Signal=FMC_D30

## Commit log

2026-06-25 chore: add and structure project-specific .gitignore files
    Move the root level .gitignore to the KiCad subdirectory and introduce specialized .gitignore files for the other subprojects.
    - Move root `.gitignore` to `KiCad/.gitignore`
    - Add `.gitignore` for `FPGA` to filter out Vivado log, journal, and run files
    - Add `.gitignore` for `VSCode/ESP32` to ignore ESP-IDF and PlatformIO build outputs
    - Add `.gitignore` for `VSCode/STM32` to ignore CMake, VS Code IPCH, and compiler outputs (ELF, BIN, HEX)
    This prevents platform-specific build artifacts and IDE cache files from cluttering the repository.
2026-06-29 feat : create KiCad project and add 5 subsheets (power, RK3568B2, DDR4, FPGA and Debug Interface)
    [DDR4.kicad_sch, Debug_Interface.kicad_sch, FPGA.kicad_sch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]
2026-07-01 feat: design 5V and 12V power rails (schematic & PCB)
    [DDR4.kicad_sch, Expansion_Port.kicad_sch, FPGA.kicad_sch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]
2026-07-08 feat : add some Expansion Ports (work in progress)
    [DDR4.kicad_sch, Expansion_Port.kicad_sch, RK3568B2.kicad_sch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]
2026-07-08 feat : add ESP32-S3-WROOM-1 (work in progress)
    [TriCore-X.kicad_pcb]
2026-07-13 refactor: change core MCU to STM32H723 and add LPDDR4/HDMI support
    [DDR4.kicad_sch, ESP32.kicad_sch, Expansion_Port.kicad_sch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]
2026-07-15 feat: complete schematic for RK809-5 PMIC peripheral circuits
    [DDR4.kicad_sch, Expansion_Port.kicad_sch, RK3568B2.kicad_sch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]
2026-08-01 refactor: update schematic components and library references, including STM32H743 and new power symbols
    [DDR4.kicad_sch, Expansion_Port.kicad_sch, MPU.kicad_sch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]
2026-08-07 refactor: update schematic components, remove unused files, and add new LED and CH334P symbols
    [DDR4.kicad_sch, ESP32.kicad_sch, Expansion_Port.kicad_sch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]
2026-08-17 Rename the board to Xeltri and drop unused T113/old-selection files.
    The KiCad project follows the rebrand; leftover T113 PDFs, the ESP32 stub, and unused HDMI/PMIC/inductor libraries are removed from the tree.
    [Debug_Interface.kicad_sch, Expansion_Port.kicad_sch, FPGA.kicad_sch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]
2026-08-17 Move STM32 firmware gitignore from VSCode/ to Code/.
    Firmware sources now live under Code/STM32 instead of VSCode/STM32.
